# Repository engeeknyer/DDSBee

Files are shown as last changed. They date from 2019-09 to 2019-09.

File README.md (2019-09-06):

# DDSBee
## microcontrolled DDS oscillator circuit with XBee footprint

This directory contains the technical and constructive report for a microcontrolled DDS oscillator circuit. The onboard microcontroller allows the programming of the oscillator in a versatile way, using an instruction set close to the user’s language. The circuit is compatible with XBee footprint. Moreover the document also contains the user documentation and examples for proper use.
The device is intended to be a basic building block for a wide range of applications, thus easing the process of electronic system’s engineering. It exhibits remarkable degrees of flexibility, which makes it amenable to a wide range of possible applications.

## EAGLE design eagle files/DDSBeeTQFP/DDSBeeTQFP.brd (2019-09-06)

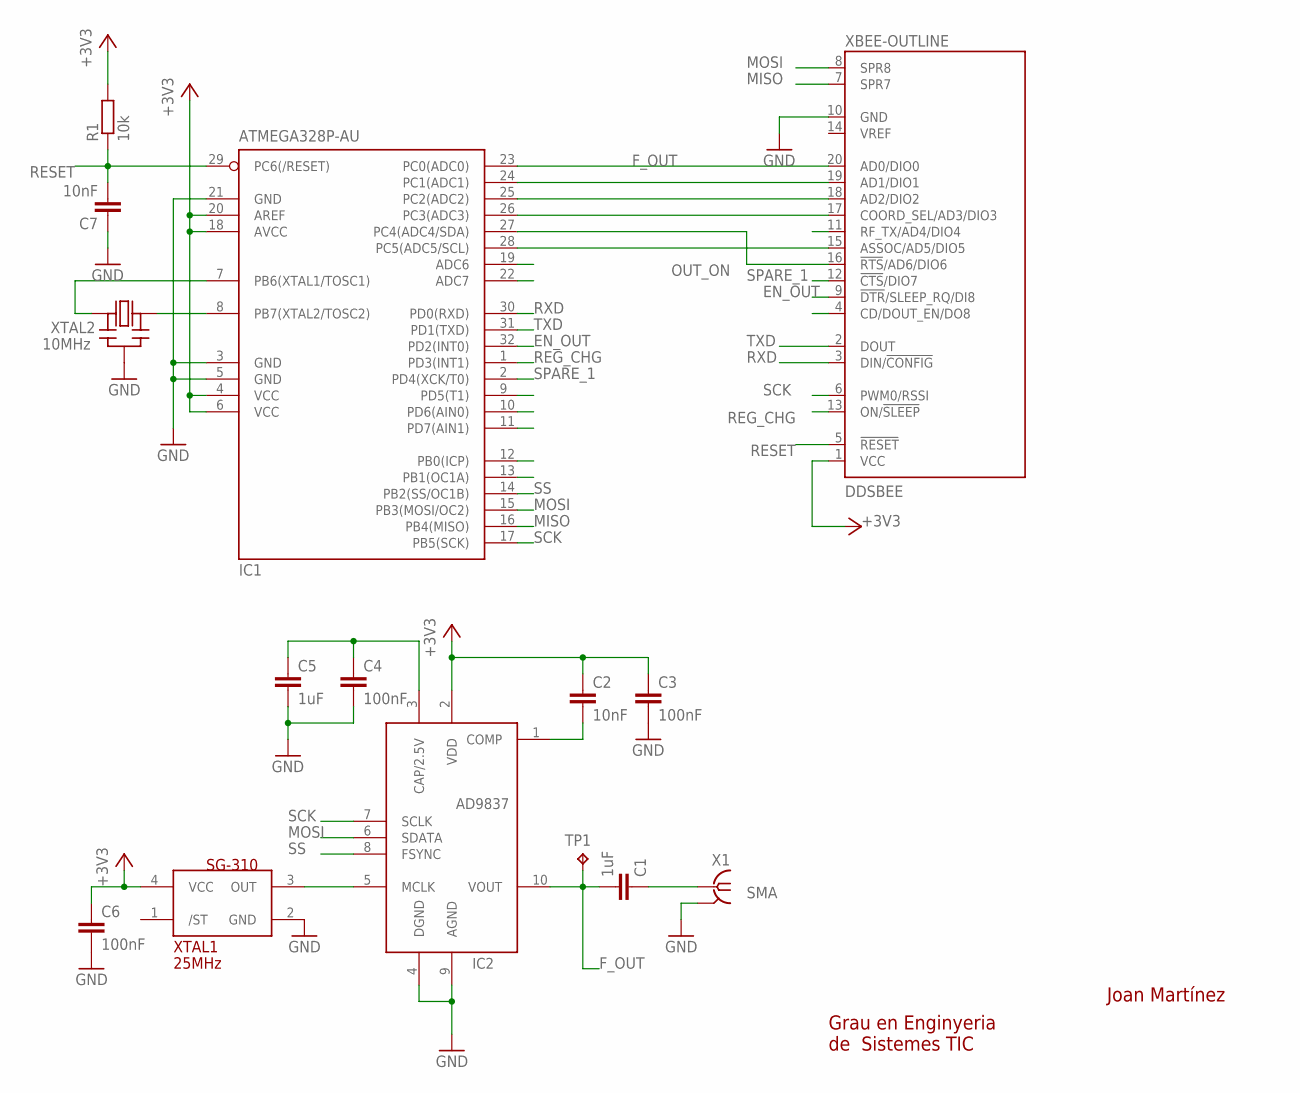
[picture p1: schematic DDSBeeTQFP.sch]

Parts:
C1, C5: 1uF; C0805
C2, C7: 10nF; C0805
C3, C4, C6: 100nF; C0805
DDSBEE: XBEE-OUTLINE; XBEE-PRO-DIM
IC1: ATMEGA328P-AU; TQFP32-08
IC2: AD9833; MSOP10
R1: 10k; R0805
TP1: TPTP15R; TP15R
X1: SMA; J502-ND-142-0701-871/876
XTAL1: 25MHz; EF241A
XTAL2: 10MHz; CERALOCK

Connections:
+3V3: C2.1, C3.1, C6.1, DDSBEE.1 (VCC), IC1.4 (VCC), IC1.6 (VCC), IC1.18 (AVCC), IC1.20 (AREF), IC2.2 (VDD), R1.2, XTAL1.4 (VCC)
EN_OUT: DDSBEE.9 (!DTR!/SLEEP_RQ/DI8), IC1.32 (PD2(INT0))
F_CON: C1.1, X1.1
F_OUT: C1.2, DDSBEE.20 (AD0/DIO0), IC1.23 (PC0(ADC0)), IC2.10 (VOUT), TP1.TP
GND: C3.2, C4.2, C5.2, C6.2, C7.1, DDSBEE.10 (GND), IC1.3 (GND), IC1.5 (GND), IC1.21 (GND), IC2.4 (DGND), IC2.9 (AGND), X1.G@1 (GND), X1.G@2 (GND), X1.G@3 (GND), X1.G@4 (GND), XTAL1.2 (GND), XTAL2.P$2 (GND)
MISO: DDSBEE.7 (SPR7), IC1.16 (PB4(MISO))
MOSI: DDSBEE.8 (SPR8), IC1.15 (PB3(MOSI/OC2)), IC2.6 (SDATA)
unnamed: IC1.8 (PB7(XTAL2/TOSC2)), XTAL2.P$3 (IN)
unnamed: C2.2, IC2.1 (COMP)
unnamed: C4.1, C5.1, IC2.3 (CAP/2.5V)
unnamed: IC1.7 (PB6(XTAL1/TOSC1)), XTAL2.P$1 (OUT)
unnamed: IC2.5 (MCLK), XTAL1.3 (OUT)
unnamed: DDSBEE.15 (ASSOC/AD5/DIO5), IC1.28 (PC5(ADC5/SCL))
unnamed: DDSBEE.19 (AD1/DIO1), IC1.24 (PC1(ADC1))
unnamed: DDSBEE.18 (AD2/DIO2), IC1.25 (PC2(ADC2))
unnamed: DDSBEE.17 (COORD_SEL/AD3/DIO3), IC1.26 (PC3(ADC3))
OUT_ON: DDSBEE.16 (!RTS!/AD6/DIO6), IC1.27 (PC4(ADC4/SDA))
REG_CHG: DDSBEE.13 (ON/!SLEEP), IC1.1 (PD3(INT1))
RESET: C7.2, DDSBEE.5 (!RESET), IC1.29 (PC6(/RESET)), R1.1
RXD: DDSBEE.3 (DIN/!CONFIG), IC1.30 (PD0(RXD))
SCK: DDSBEE.6 (PWM0/RSSI), IC1.17 (PB5(SCK)), IC2.7 (SCLK)
SPARE_1: DDSBEE.12 (!CTS!/DIO7), IC1.2 (PD4(XCK/T0))
SS: IC1.14 (PB2(SS/OC1B)), IC2.8 (FSYNC)
TXD: DDSBEE.2 (DOUT), IC1.31 (PD1(TXD))

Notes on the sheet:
Joan Martínez
Grau en Enginyeria de Sistemes TIC

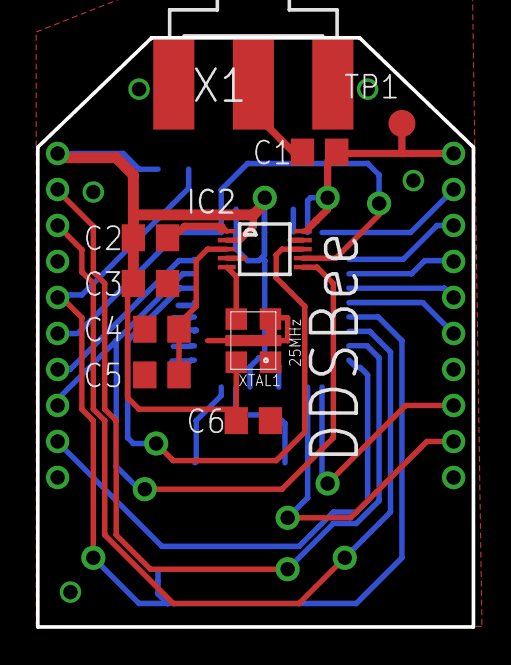
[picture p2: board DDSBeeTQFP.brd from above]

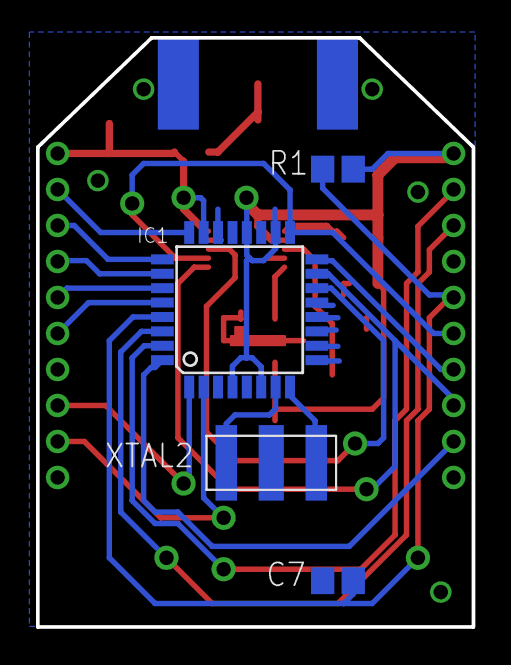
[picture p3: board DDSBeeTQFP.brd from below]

Board: 2 copper layers, 24.2 x 32.7 mm, 15 parts (4 on the bottom side), 24 nets.

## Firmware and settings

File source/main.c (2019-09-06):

#include <stdio.h>
#include <stdbool.h>
#include <avr/pgmspace.h>

#include "serial.h"
#include "shell.h"
#include "flasherror.h"

#define PROMT "> "             // Estableix promt de la línia de comandes
#define CENTINELLA '\n'        // Estableix caràcter utilitzat com a centinella
#define LEN_MSG_MAX 30         // Estableix la mida màxima dels missatges


uint8_t msg_entrada[LEN_MSG_MAX];
uint8_t * pnt_msg_e=msg_entrada;
uint8_t msg_processat[LEN_MSG_MAX];
uint8_t * pnt_msg_p=msg_processat;
uint8_t punter=0;

static void setup(void);
static void loop(void);

int main(void){
  /*******************************
        PROGRAMA PRINCIPAL
        ------------------
    Estructura el funcionament del 
   programa en la funció setup() i
   la funció loop() 
  ********************************/
  setup();
  while(true) loop();
  return 0;
}

static void setup(void){
  /****************************
         CONFIGURACIONS
         --------------
    Configura les característiques de 
  comunicació i els diferents mòduls 
  per treballar amb ells.
  *****************************/
  serial_init();
  shell_init();
  serial_print(PROMT);
}

static void loop(void){
  /****************************
    PROGRAMA CÍCLIC PRINCIPAL
    -------------------------
  *****************************/

  int8_t value;
  char buffer[20];

  if(serial_can_read()){
    uint8_t c= serial_get();
    if(c!=CENTINELLA){
      msg_entrada[punter++] = c;
    }else{
      msg_entrada[punter] = 0;
      value=process_command(pnt_msg_e);
      if(value<0){
	value=1+~value;
	GET_ERROR(buffer,value);
	serial_print(buffer);
      }
      punter=0;
      serial_print(PROMT);
    }
  }
}

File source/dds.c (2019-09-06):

#include <stdint.h>
#include <inttypes.h>
#include "spibus.h"
#include "dds.h"

/*   Límits màxims de freq. i fase 
     -----------------------------
     TO-DO: Automatitzar des de compilació
*/
#define DDS_F_MAX 12500000L
#define DDS_PH_MAX 359 


/*   Multiplicadors de Freqüència i Fase
     -----------------------------------
     Es trien diferents multiplicadors en funció de la
freqüència de MCLK. 

  - FREQ_MUL 
    clk= 5MHz 53.6870912
    clk=16Mhz 16.777216f
    clk=25Mhz 10.73741824f

    Per el multiplicador de fase es tria en funció de les
unitats del valor d'entrada
 
    11.3777778f per graus
    651.8986469f per radians
*/
#define FREQ_MUL 10.73741824f
#define PHSE_MUL 11.3777778f

/*  Constants de Registres de Control
    ---------------------------------
  Aquests són els valors de les constants necessàries per 
programar els registres de el DDS.
*/
#define SIN_WF 0x00
#define SQR_WF 0x28
#define TRI_WF 0x02
#define SLEEP1 0x80 

#define RESET_WD 0x0100
#define START_WD 0x2000
#define SET_F_WD 0x2100
#define PHSE_MSK 0xC000

#define FSEL0 0x0000
#define FSEL1 0x0800

#define PSEL0 0x0000
#define PSEL1 0x0400


#define FSEL_MSK 0xF7FF
#define PSEL_MSK 0xFBFF
#define RST_MSK 0xFEFF
#define SLEP_MSK 0xFF7F
#define WF_MSK 0xFFD5

#define START_F0 START_WD|FSEL0
#define START_F1 START_WD|FSEL1
#define START_MSK 0xD6FF

/*  Constants dels Registres de Frequencies
    ---------------------------------------
  Per seleccionar en quin registre (0 o 1) volem programar les paraules de 
14 bits (LSB o MSB).
*/
#define FREQ0 0x4000
#define FREQ1 0x8000

/*  Constants dels Registres de Fase
    --------------------------------
  Per seleccionar en quin registre (0 o 1) volem programar les paraules de 
12 bits per la fase.
*/
#define PHASE0 0xC000
#define PHASE1 0xE000


uint16_t control_reg=START_WD;
uint32_t freq0_reg;
uint32_t freq1_reg;
uint16_t fase0_reg;
uint16_t fase1_reg;



/*   CAPÇALERES FUNCIONS PRIVADES   
     ----------------------------           */
static int8_t DDS_SetDirectFrequency(uint32_t frequency, const uint16_t freq_reg);
static int8_t DDS_SetFrequency(uint32_t frequency, const uint16_t freq_reg);
static int8_t DDS_SetPhase(const uint16_t phase, const uint16_t phase_reg);
static int8_t DDS_ChgControlReg(const uint16_t reg_mask, const uint16_t reg_value);



/*     FUNCIONS PÚBLIQUES
       ------------------                       */
uint32_t DDS_GetFreqR0(void){
  /* Retorna el contingut de la copia del 
     registre de freqüència del DDS  */
  return freq0_reg;
}

uint32_t DDS_GetFreqR1(void){
  /* Retorna el contingut de la copia del 
     registre de freqüència 1 del DDS  */
  return freq1_reg;
}

uint16_t DDS_GetPhaseR0(void){
  /* Retorna el contingut de la copia del 
     registre de fase 0 del DDS  */
  return fase0_reg;
}

uint16_t DDS_GetPhaseR1(void){
  /* Retorna el contingut de la copia del 
     registre de fase 1 del DDS  */
  return fase1_reg;
}

uint16_t DDS_GetCtlReg(void){
  /* Retorna el contingut de la copia del 
     registre de control del DDS  */
  return control_reg;
}

void DDS_Reset(void){
  /* Resets output (not registers)
     output is held in middle value */
  DDS_ChgControlReg(RST_MSK, RESET_WD);
}

void DDS_Start(void){
  /* Posa en marxa la sortida mantenint 
     els bits PSEL FSEL sense alterar */
  DDS_ChgControlReg(RST_MSK, START_WD);
}


void DDS_SetCtlReg(const uint16_t reg){
  /* Estableix el valor de registre de 
     control i de la seva copia */
  DDS_ChgControlReg(0x0000, reg);
}

void DDS_Init(void){
  /* Prepara Master Device 
     i atura DDS */ 
  SPI_MasterInit();
  SPI_Active();
  DDS_Reset();
  SPI_Idle();
}

void DDS_Start_0(void){
  /* Enables DDS Output */
  DDS_ChgControlReg(START_MSK, START_F0);
}

void DDS_Start_1(void){
  /* Enables DDS Output */
  DDS_ChgControlReg(START_MSK, START_F1);
}


void DDS_Freq_0(void){
  /* Select FR0 */
  DDS_ChgControlReg(FSEL_MSK, FSEL0);
}

void DDS_Freq_1(void){
  /* Select FR1 */
  DDS_ChgControlReg(FSEL_MSK, FSEL1);
}

void DDS_Phase_0(void){   
  DDS_ChgControlReg(PSEL_MSK, PSEL0);
}

void DDS_Phase_1(void){
  DDS_ChgControlReg(PSEL_MSK, PSEL1);
}

void DDS_Sine(void){ 
  DDS_ChgControlReg(WF_MSK, SIN_WF);
}

void DDS_Square(void){
  DDS_ChgControlReg(WF_MSK, SQR_WF);
}

void DDS_Triangle(void){
  DDS_ChgControlReg(WF_MSK, TRI_WF);
}


int8_t DDS_SetPhase_0(const uint16_t phase){
  /* Estableix el valor de fase del registre de fase 0 */
  int8_t value=DDS_SetPhase(phase, PHASE0);
  if (!value) fase0_reg=phase;
  return value;
}

int8_t DDS_SetPhase_1(const uint16_t phase){
  /* Estableix el valor de fase del registre de fase 1 */
  int8_t value=DDS_SetPhase(phase, PHASE1);
  if (!value) fase1_reg=phase;
  return value;
}

int8_t DDS_SetFreq_0(uint32_t frequency){
  /* Estableix el valor de frequencia del registre de frequencia 0 */
  int8_t value=DDS_SetFrequency(frequency, FREQ0);
  if (!value) freq0_reg=frequency;
  return value;
}

int8_t DDS_SetFreq_1(uint32_t frequency){
  /* Estableix el valor de frequencia del registre de frequencia 1 */
  int8_t value=DDS_SetFrequency(frequency, FREQ1);
  if (!value) freq1_reg=frequency;
  return value;
}


/*     FUNCIONS PRIVADES
       -----------------                       */
int8_t DDS_SetDirectFrequency(uint32_t frequency, const uint16_t freq_reg){
  /* Sets a new frequency without 
     reseting the output */
  if(frequency<=12500000){
    uint32_t divisor=frequency*FREQ_MUL;
    SPI_Master16bTransmit((divisor & 0x3fff)| freq_reg);
    SPI_Master16bTransmit((divisor >> 14) | freq_reg);
    return 0;
  }
  else{
    return -3;
  }
}

int8_t DDS_SetFrequency(uint32_t frequency, const uint16_t freq_reg){
  /* Sets a new frequency reseting 
     previously the output */
    SPI_Master16bTransmit(SET_F_WD);
    return DDS_SetDirectFrequency(frequency,freq_reg);
}

int8_t  DDS_SetPhase(const uint16_t phase, const uint16_t phase_reg){
  /* Sets a new phase */
  if(phase<=DDS_PH_MAX){
    SPI_Master16bTransmit((uint16_t)(phase*PHSE_MUL) | phase_reg);
    return 0;
  }
  else
    return -3;
}

static int8_t DDS_ChgControlReg(const uint16_t reg_mask, const uint16_t reg_value){
  /* Funció que s'encarrega de modificar el registre de control 
     del DDS i guardar una copia */
  control_reg = (control_reg & reg_mask) | reg_value;
  SPI_Master16bTransmit(control_reg);
  return 0;
}
